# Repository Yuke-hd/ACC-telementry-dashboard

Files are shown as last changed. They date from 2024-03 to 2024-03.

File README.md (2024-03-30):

# ACC-telemetry-dashboard
Poor man's simrace dashboard for Assetto Corsa Competizione
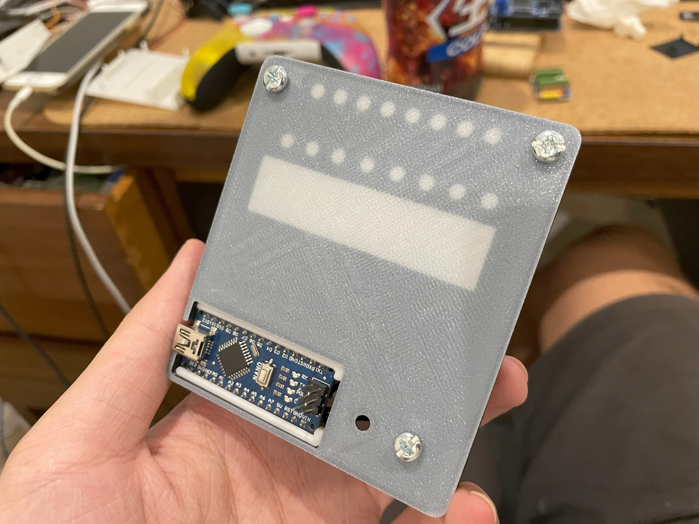
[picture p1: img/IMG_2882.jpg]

## See it in action
Preview (https://youtu.be/b4wcGJOdnoc)

# Overview
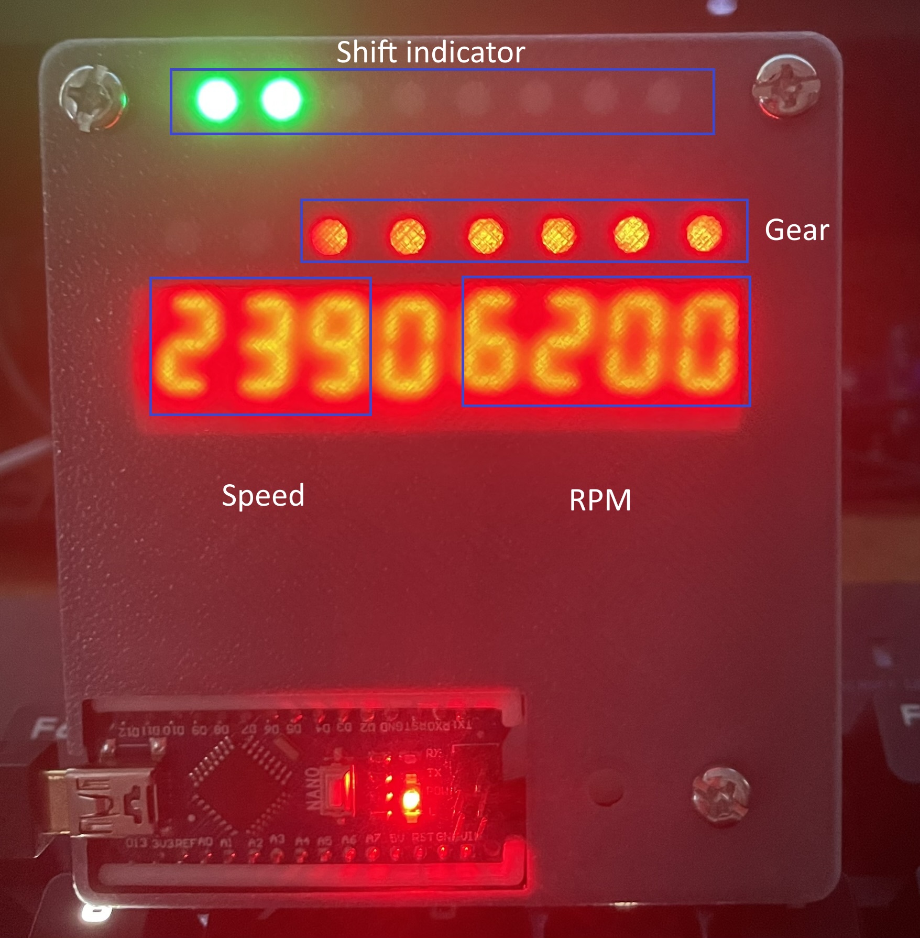
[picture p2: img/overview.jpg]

# Reqirements
1. Python 3.8
2. VScode + PlatformIO extension

## Hardware
1. Arduino Nano compatiable boards
2. TM1638 LED&KEY module ([Link](https://www.aliexpress.com/item/1005006579759157.html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))
3. 8 bit ws2812b led module
4. 3D printed case
5. M3/M4 x 20 or longer screws and nuts

## Wiring
Remove the headers on the TM1638 board, solder wires directly on the soldering pads to save space.

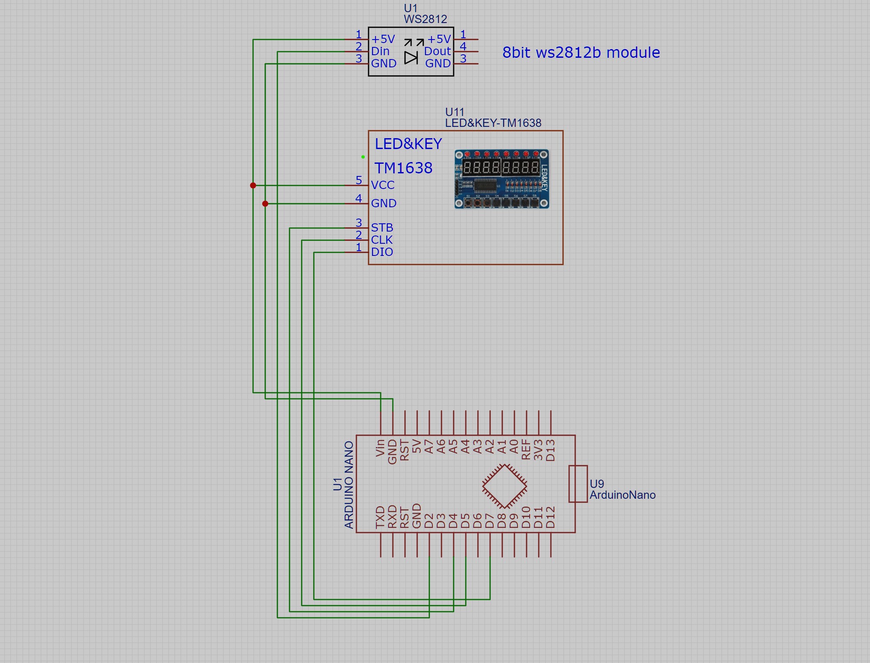
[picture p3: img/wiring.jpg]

This is base on my pin setting in code, 
```
// TM1638 setup
#define STROBE_TM 4     // strobe = GPIO connected to strobe line of module
#define CLOCK_TM 5      // clock = GPIO connected to clock line of module
#define DIO_TM 7        // data = GPIO connected to data line of module
// WS2812 setup
const int ledPin = 2;
```

# Installation
## Python
In `src/main.py` Change `COM_PORT` to the port used to connect to the dashboard

then
```
pip install -r requirements.txt
```
## Arduino
Use VSCode to upload `src/acc_telementry.cpp`

You can also use Arduino IDE the upload the code, but you need to make some small changes to the code ([example](https://stackoverflow.com/questions/55684371/how-do-i-add-cpp-file-to-an-arduino-project))

# Usage
Connect the dashboard to PC
```
python main.py
```

# Customization
TBA

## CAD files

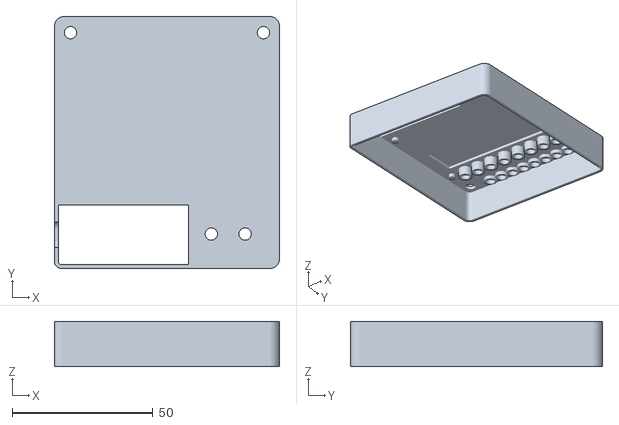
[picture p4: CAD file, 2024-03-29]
stl/cover.stl
80.0 x 89.5 x 16.1

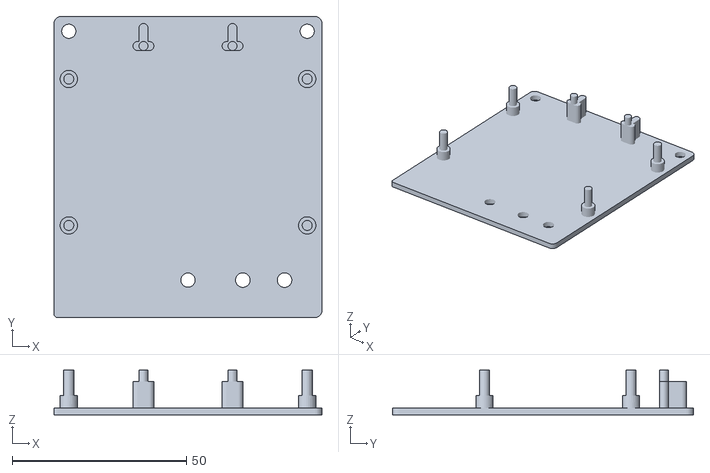
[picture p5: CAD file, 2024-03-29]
stl/base.stl
77.0 x 86.5 x 12.9

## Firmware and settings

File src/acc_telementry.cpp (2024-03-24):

#include <Arduino.h>
#include <Adafruit_NeoPixel.h>
#include <TM1638plus.h>

// TM1638 setup
#define STROBE_TM 4     // strobe = GPIO connected to strobe line of module
#define CLOCK_TM 5      // clock = GPIO connected to clock line of module
#define DIO_TM 7        // data = GPIO connected to data line of module
bool high_freq = false; // default false,, If using a high freq CPU > ~100 MHZ set to true.
TM1638plus tm(STROBE_TM, CLOCK_TM, DIO_TM, high_freq);

struct DataPacket
{
  float rpm;
  float gear;
  float spd;
  float max_rpm;
};

#define BUFFER_SIZE 16 // 4 * 4 floats

// WS2812 setup
const int ledPin = 2;
const int numLeds = 8; 
const int delta = 256 / numLeds;
int lastNum = 0;
const int fps = 16;
#define RED_ZONE 8
#define YELLOW_ZONE 6
#define GREEN_ZONE 4

Adafruit_NeoPixel strip = Adafruit_NeoPixel(numLeds, ledPin, NEO_GRB + NEO_KHZ800);

float rpm;
uint16_t last_gear;
float led;
int max_rpm = 7000;

void tachometer(int rpm);
uint32_t getColor(int ledPos);

void setup()
{
  strip.begin();
  strip.setBrightness(20); // 1/3 brightness
  Serial.begin(115200);
  tm.displayBegin();
}

void loop()
{
  DataPacket data;

  if (Serial.available() >= BUFFER_SIZE)
  {
    uint8_t buffer[BUFFER_SIZE];

    Serial.readBytes(buffer, BUFFER_SIZE);

    memcpy(&data, buffer, BUFFER_SIZE);

    float toDisplay = int(data.rpm) + int(data.spd) * 100000;
    tm.displayIntNum(toDisplay, true, TMAlignTextRight); 
    
    uint16_t gear = uint16_t(data.gear);
    if (last_gear != gear)
    {
      tm.setLEDs(gear);
      last_gear = gear;
    }

    max_rpm = int(data.max_rpm) - 500;
    float k = (((data.rpm - max_rpm * 0.8) * numLeds) / (max_rpm * 0.2)) + 0;
    tachometer(int(k));


    while (Serial.read() > 0)
    {
    }
  }
}

void tachometer(int rpm)
{
  if (rpm < 0)
  {
    return;
  }
  if (rpm > numLeds)
  {
    return;
  }
  if (rpm < lastNum)
  {
    for (int x = strip.numPixels() - 1; x >= 0; x--)
    {
      if (x < rpm)
      {
        strip.setPixelColor(x, getColor(x));
      }
      else
      {
        strip.setPixelColor(x, 0);
      }
      strip.show();
    }
  }
  else
  {
    for (uint8_t x = 0; x < strip.numPixels(); x++)
    {
      if (x < rpm)
      {
        strip.setPixelColor(x, getColor(x));
      }
      else
      {
        strip.setPixelColor(x, 0);
      }
      strip.show();
    }
  }
  lastNum = rpm;
}

uint32_t getColor(int ledPos)
{
  
  if (ledPos < GREEN_ZONE)
  {
    return strip.Color(0, 255, 0); // green
  }
  else if (ledPos >= GREEN_ZONE && ledPos < YELLOW_ZONE)
  {
    return strip.Color(255, 255, 0); // yellow
  }
  else
  {
    return strip.Color(255, 0, 0); // red
  }
}

// Input a value 0 to 255 to get a color value.
// The colours are a transition r - g - b - back to r.
uint32_t Wheel(byte WheelPos)
{
  if (WheelPos < 85)
  {
    return strip.Color(WheelPos * 3, 255 - WheelPos * 3, 0);
  }
  else if (WheelPos < 170)
  {
    WheelPos -= 85;
    return strip.Color(255 - WheelPos * 3, 0, WheelPos * 3);
  }
  else
  {
    WheelPos -= 170;
    return strip.Color(0, WheelPos * 3, 255 - WheelPos * 3);
  }
}

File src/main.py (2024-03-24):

from typing import Final
from pyaccsharedmemory import accSharedMemory
import time
import struct
import serial

REFRESH_INTERVAL: Final[int] = 50 # in ms
COM_PORT: Final[str] = "COM10"
BAUD_RATE: Final[int] = 115200


def fill_leftmost_bits(x: int):
    if x <= 0:
        return 0
    # Create a mask with x leftmost bits set to 1
    mask = (1 << x) - 1

    # Shift the mask to the left by the number of bits in the integer
    mask <<= 16 - x

    # Apply the mask to the value
    result = 0x0000 | mask

    return result


def main():
    try:
        arduinoSerial = serial.Serial(COM_PORT, BAUD_RATE)
    except serial.SerialException:
        print("unable to open port {}".format(COM_PORT))
        return

    asm = accSharedMemory()

    last_ms = time.time() * 1000.0

    try:
        while True:            
            ms = time.time() * 1000.0

            if ms - last_ms > REFRESH_INTERVAL:
                sm = asm.read_shared_memory()
                if sm is None:
                    continue

                rpm = float(sm.Physics.rpm)
                gear = float(fill_leftmost_bits(sm.Physics.gear - 1))
                spd = float(sm.Physics.speed_kmh)
                max_rpm = float(sm.Static.max_rpm)

                if arduinoSerial.writable():
                    arduinoSerial.write(struct.pack("ffff", rpm, gear, spd, max_rpm))
                
                last_ms = ms

    except KeyboardInterrupt:
        asm.close()
    except serial.SerialException:
        print("unable to send data to port {}, is the hardward connected?".format(COM_PORT))
        return


if __name__ == "__main__":
    main()

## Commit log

2024-03-29 Adding wiring diagram
2024-03-29 Adding 3d printing file
    [base.stl, cover.stl]
2024-03-30 Adding link to 3d printed case files
